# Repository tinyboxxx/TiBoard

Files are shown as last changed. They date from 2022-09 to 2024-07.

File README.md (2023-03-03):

# TiBoard
>  TiBoard的硬件部分及说明文件

- merged SofleKeyboard and nrfBoard
- reserved place for trackpoint
- position of keys moved to my hand measurements
- carbon fiber top plate
- Voronoi style 3D print keycap

打包的KiCAD如果有什么问题麻烦发issue。

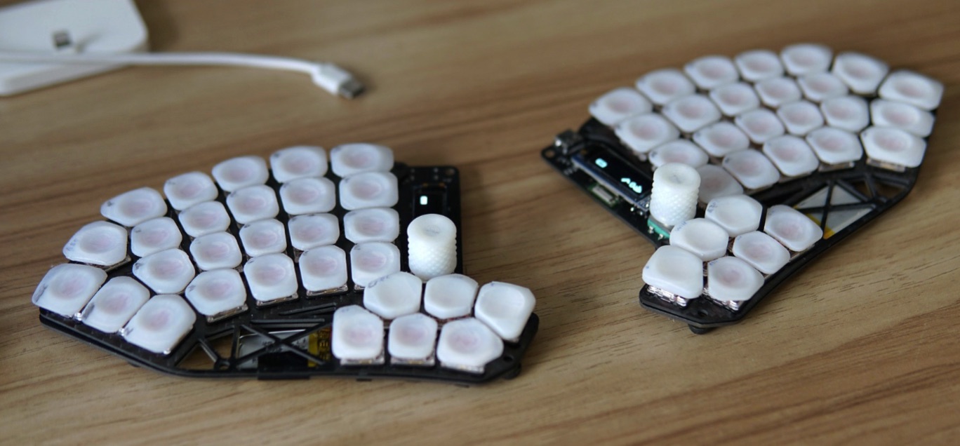
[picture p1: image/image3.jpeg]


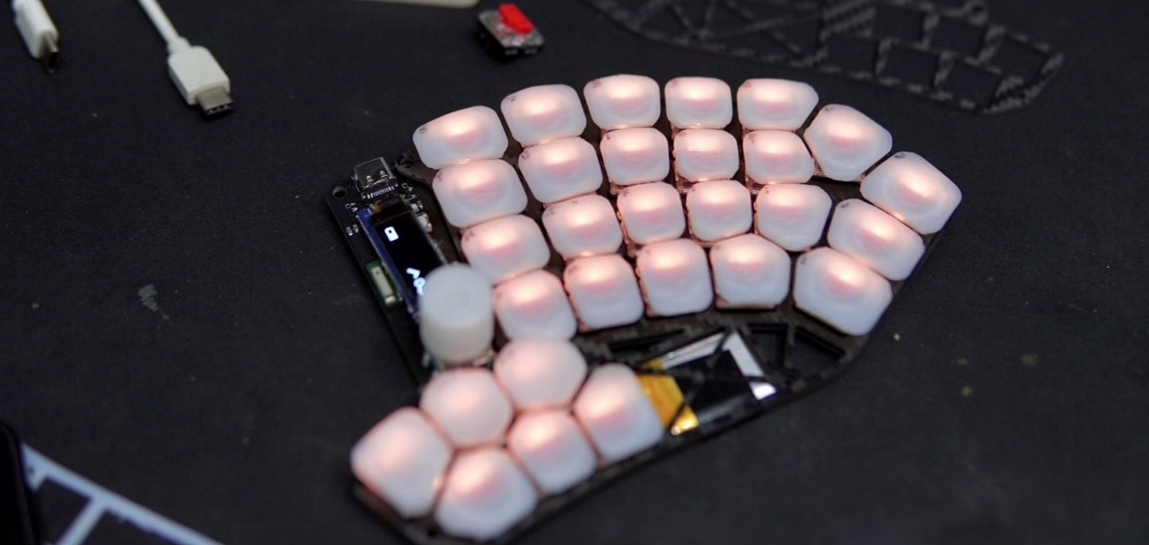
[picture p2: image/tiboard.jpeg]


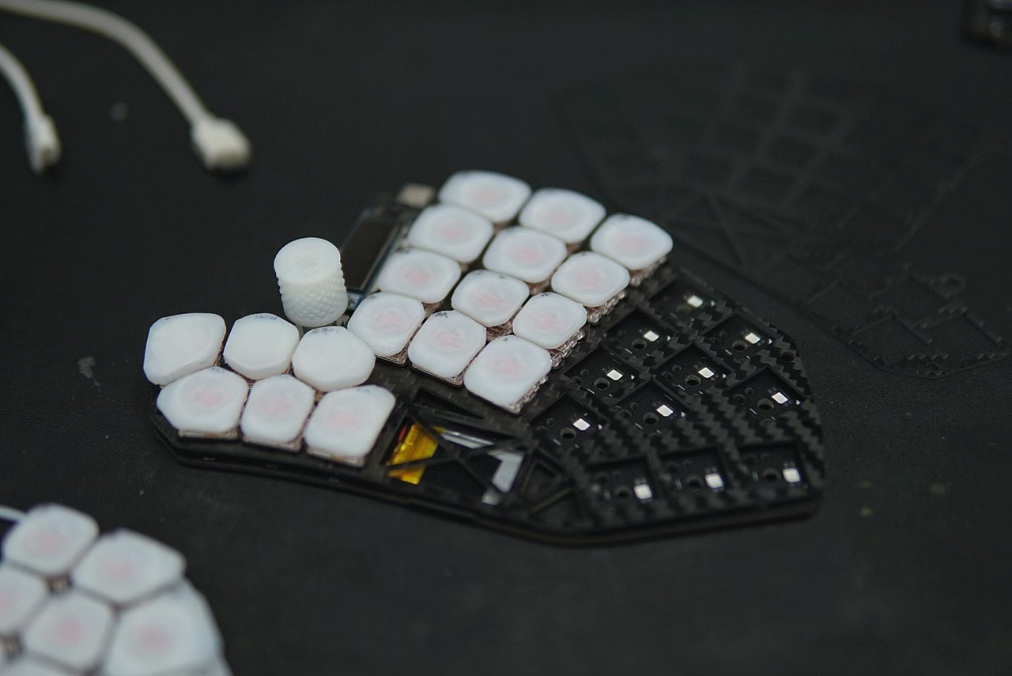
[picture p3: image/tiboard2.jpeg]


## 许可

可以自己随便做着玩。

空板交易无所谓，不要闲鱼卖套件，不要卖成品。

转载和修改版请带上我的名字。

## 需要注意购买的零件

**注意：为单套，左右手两只的数量需要x2 ！**

| 项目 | 备注 | 数量（单个板） | 链接 |
| --- | --- | --- | --- |
| E73蓝牙模块（PCB内） | E73-2G4M08S1C | 1 | https://m.tb.cn/h.UL6DjRC  亿佰特nRF52840/52833芯片无线蓝牙MESH模块BLE4.2/5.0陶瓷天线 |
| 锂电池 | 402030（长30宽20厚4）不一定非要这家店，同尺寸带保护板即可。  | 1 | https://m.tb.cn/h.Upcs7Os  伯朗 导航行车记录仪锂电池大容量通用3.7v聚合物 |
| 轴体 | 必须凯华1350型号，颜色任选 | 30 | https://m.tb.cn/h.UK0Awu7  凯华Kailh 1350巧克力机械键盘轴体  |
| 轴体热插拔底座 | 必须凯华1350型号 | 30 | https://item.taobao.com/item.htm?id=667154671807 |
| 定位板 | 厚度1.2mm，dxf文件见附件，参考价格碳纤维RMB68两片。也可以使用玻纤等其他不导电材料。 | 1 | https://item.taobao.com/item.htm?id=40340403528 |

## 状态及已知问题

BOM里充电电流设定用的R9 现在用的是2.2K，二极管是1N4148WS。

有其他疑问也请发issue。

已知问题：

- 目前使用的电池功耗大约1至2天，建议随时充电。
- 键位比较少 符号和其他按键不大方便。
- reset按钮位置比较难按。
- USB Type-C接口没有做沉板，左手的接口比较靠近桌子。
- 电池接插件比较大，目前直接焊线。
- I2C的两个电阻实测可以不焊接。
- 烧录E73模块真的很麻烦，需要先刷ST-LINK的固件 或者用STM32
- 指点杆的安装比较麻烦，而且可能影响厚度，兼容性还未测试。

## 链接

固件 https://github.com/tinyboxxx/zmk-config

固件下载 https://github.com/tinyboxxx/zmk-config/actions

键位编辑器 [ZMK Keymap Editor (nickcoutsos.github.io)](https://nickcoutsos.github.io/keymap-editor/)

视频 https://www.bilibili.com/video/BV1qe4y1t7zE/

烧录bootloader https://github.com/joric/nrfmicro/wiki/Bootloader#nrf52840

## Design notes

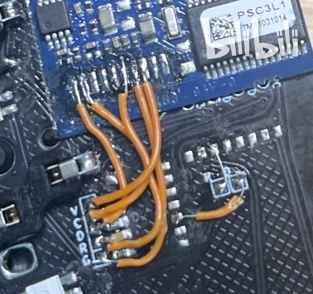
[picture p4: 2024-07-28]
Tiboard/Snipaste_2024-07-28_22-50-21.png

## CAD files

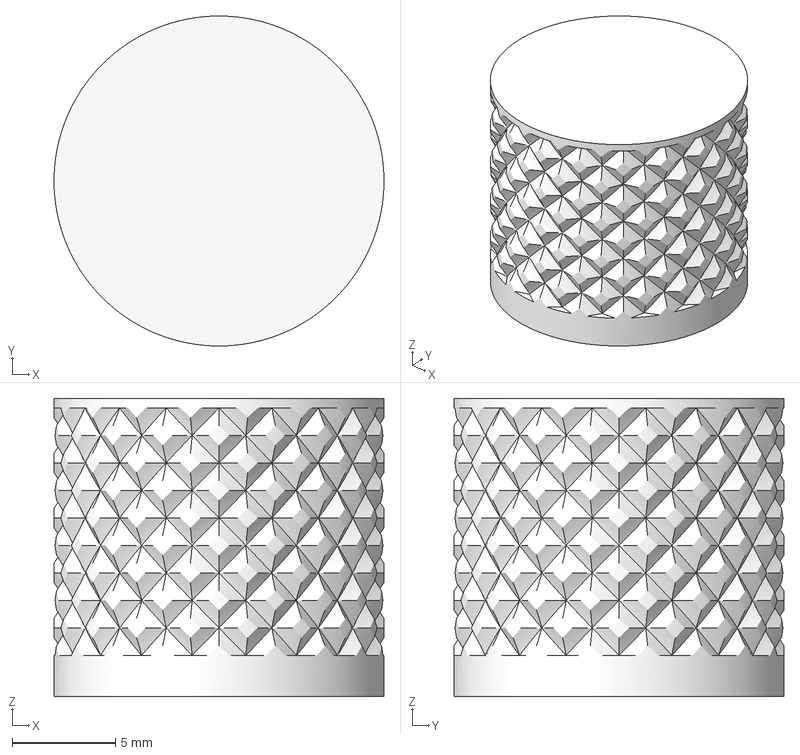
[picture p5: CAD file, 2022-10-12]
2. 3D - Fusion360/编码器帽.3mf
16.0 x 16.0 x 14.5 mm

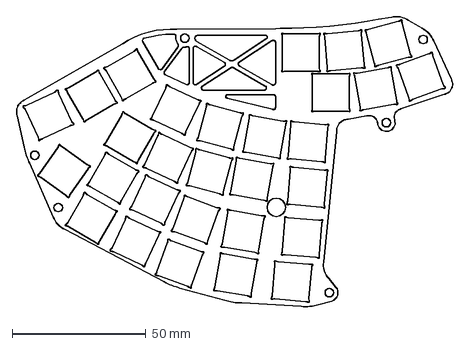
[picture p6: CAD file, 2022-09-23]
3. Top Board - DXF/1.2mm厚度 两个 正反面.dxf
162.9 x 108.4 mm

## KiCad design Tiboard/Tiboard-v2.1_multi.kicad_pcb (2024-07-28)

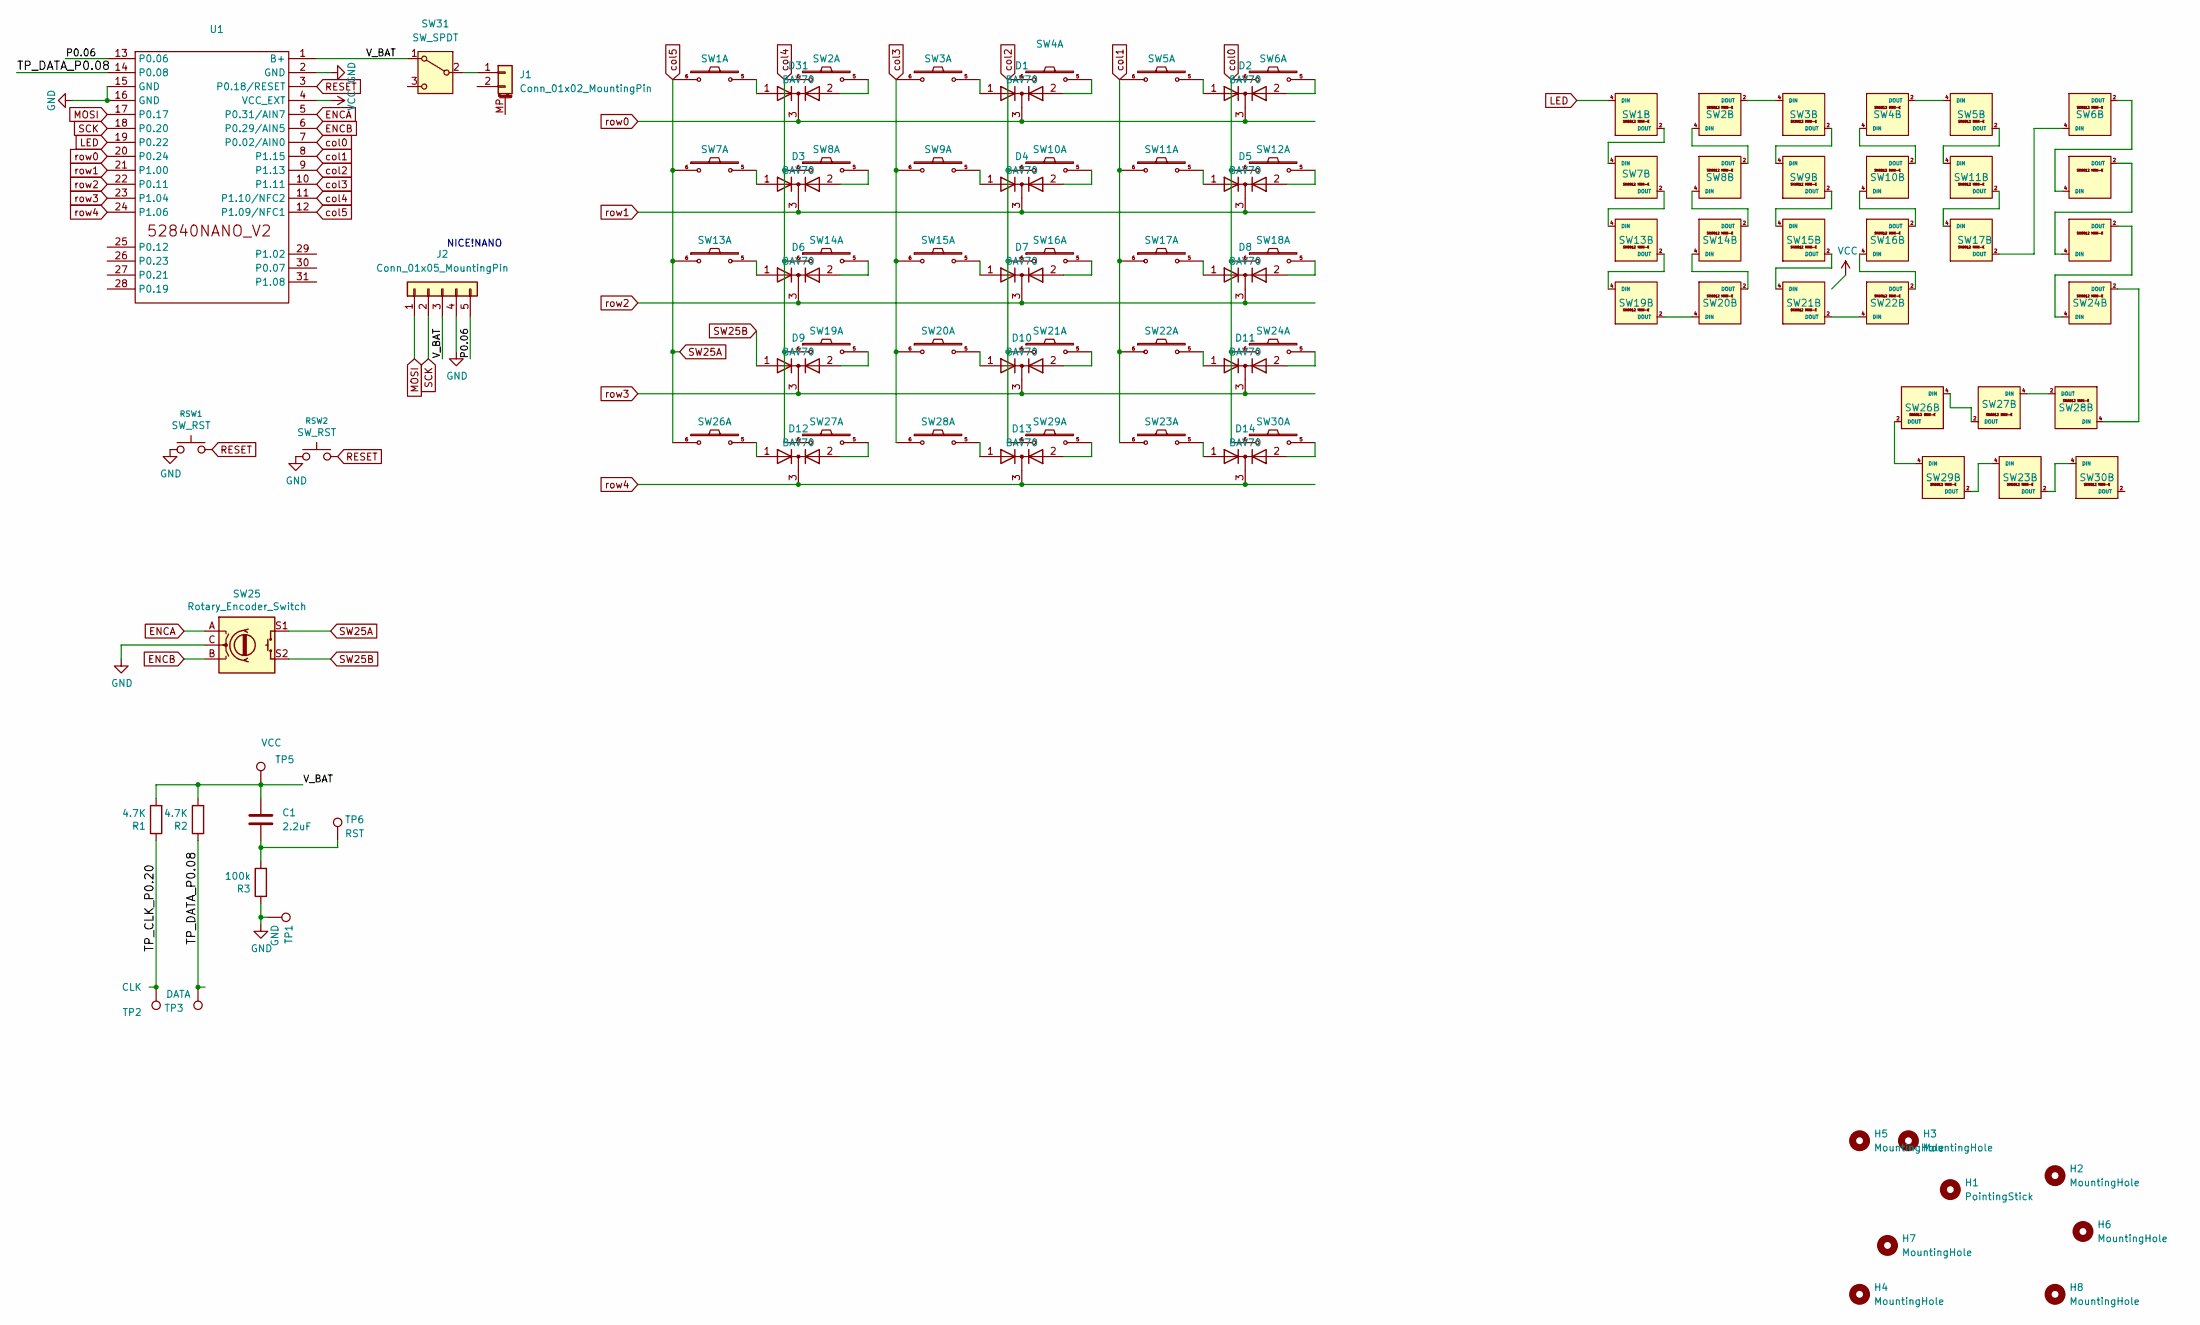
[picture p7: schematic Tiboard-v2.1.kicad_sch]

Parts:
C1: 2.2uF; C_0603_1608Metric
D1, D2, D3, D4, D5, D6, D7, D8, D9, D10, D11, D12, D13, D14, D31: BAV70; SOT-23
H1: PointingStick; Pointing_Stick
H2, H3, H4, H5, H6, H7, H8: MountingHole; MountingHole_3.2mm_M3_Pad_Via
J1: Conn_01x02_MountingPin; JST_SHL_SM02B-SHLS-TF_1x02-1MP_P1.00mm_Horizontal
J2: Conn_01x05_MountingPin; NICEVIEW_5Pin
R1, R2: 4.7K; R_0603_1608Metric
R3: 100k; R_0603_1608Metric
RSW1, RSW2: SW_RST; SW_SPST_CK_KXT3
SW1, SW2, SW3, SW4, SW5, SW6, SW7, SW8, SW9, SW10, SW11, SW12, SW13, SW14, SW15, SW16, SW17, SW18, SW19, SW20, SW21, SW22, SW23, SW24, SW26, SW27, SW28, SW29, SW30: SW_PUSH_LED; TTC_mini
SW25: Rotary_Encoder_Switch; RotaryEncoder_Alps_EC11E-Switch_Vertical_H20mm-keebio_modif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
SW31: SW_SPDT; SW_Slide_SPDT_Angled_CK_OS102011MA1Q
TP1: GND; TestPoint_Pad_1.0x1.0mm
TP2: CLK; TestPoint_Pad_1.0x1.0mm
TP3: DATA; TestPoint_Pad_1.0x1.0mm
TP5: VCC; TestPoint_Pad_1.0x1.0mm
TP6: RST; TestPoint_Pad_1.0x1.0mm
U1: 52840NANO_V2

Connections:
/P0.06: J2.5, U1.13 (P0.06)
ENCA: SW25.A, U1.5 (P0.31/AIN7)
ENCB: SW25.B, U1.6 (P0.29/AIN5)
LED: SW1.4 (DIN), U1.19 (P0.22)
unnamed: C1.2, R3.2, TP6.1
unnamed: D1.1 (A), SW3.5
unnamed: D1.2 (A), SW4.5
unnamed: D2.1 (A), SW5.5
unnamed: D2.2 (A), SW6.5
unnamed: D3.1 (A), SW7.5
unnamed: D3.2 (A), SW8.5
unnamed: D4.1 (A), SW9.5
unnamed: D4.2 (A), SW10.5
unnamed: D5.1 (A), SW11.5
unnamed: D5.2 (A), SW12.5
unnamed: D6.1 (A), SW13.5
unnamed: D6.2 (A), SW14.5
unnamed: D7.1 (A), SW15.5
unnamed: D7.2 (A), SW16.5
unnamed: D8.1 (A), SW17.5
unnamed: D8.2 (A), SW18.5
unnamed: D9.2 (A), SW19.5
unnamed: D10.1 (A), SW20.5
unnamed: D10.2 (A), SW21.5
unnamed: D11.1 (A), SW22.5
unnamed: D11.2 (A), SW24.5
unnamed: D12.1 (A), SW26.5
unnamed: D12.2 (A), SW27.5
unnamed: D13.1 (A), SW28.5
unnamed: D13.2 (A), SW29.5
unnamed: D14.1 (A), SW23.5
unnamed: D14.2 (A), SW30.5
unnamed: D31.1 (A), SW1.5
unnamed: D31.2 (A), SW2.5
unnamed: J1.1, SW31.2 (B)
unnamed: SW1.2 (DOUT), SW7.4 (DIN)
unnamed: SW2.4 (DIN), SW8.2 (DOUT)
unnamed: SW2.2 (DOUT), SW3.4 (DIN)
unnamed: SW3.2 (DOUT), SW9.4 (DIN)
unnamed: SW4.2 (DOUT), SW5.4 (DIN)
unnamed: SW10.4 (DIN), SW16.2 (DOUT)
unnamed: SW4.4 (DIN), SW10.2 (DOUT)
unnamed: SW5.2 (DOUT), SW11.4 (DIN)
unnamed: SW11.2 (DOUT), SW17.4 (DIN)
unnamed: SW6.2 (DOUT), SW12.4 (DIN)
unnamed: SW12.2 (DOUT), SW18.4 (DIN)
unnamed: SW7.2 (DOUT), SW13.4 (DIN)
unnamed: SW13.2 (DOUT), SW19.4 (DIN)
unnamed: SW14.4 (DIN), SW20.2 (DOUT)
unnamed: SW8.4 (DIN), SW14.2 (DOUT)
unnamed: SW9.2 (DOUT), SW15.4 (DIN)
unnamed: SW15.2 (DOUT), SW21.4 (DIN)
unnamed: SW16.4 (DIN), SW22.2 (DOUT)
unnamed: SW6.4 (DIN), SW17.2 (DOUT)
unnamed: SW18.2 (DOUT), SW24.4 (DIN)
unnamed: SW19.2 (DOUT), SW20.4 (DIN)
unnamed: SW21.2 (DOUT), SW22.4 (DIN)
unnamed: SW23.4 (DIN), SW29.2 (DOUT)
unnamed: SW23.2 (DOUT), SW30.4 (DIN)
unnamed: SW24.2 (DOUT), SW28.4 (DIN)
unnamed: SW26.4 (DIN), SW27.2 (DOUT)
unnamed: SW26.2 (DOUT), SW29.4 (DIN)
unnamed: SW27.4 (DIN), SW28.2 (DOUT)
RESET: RSW1.2, RSW2.2, U1.3 (P0.18/RESET)
SCL: J2.2, U1.18 (P0.20)
SDA: J2.1, U1.17 (P0.17)
SW25A: SW1.6, SW7.6, SW13.6, SW25.S1, SW26.6, U1.12 (P1.09/NFC1)
SW25B: D9.1 (A), SW25.S2
VCC: SW1.1 (VDD), SW2.1 (VDD), SW3.1 (VDD), SW4.1 (VDD), SW5.1 (VDD), SW6.1 (VDD), SW7.1 (VDD), SW8.1 (VDD), SW9.1 (VDD), SW10.1 (VDD), SW11.1 (VDD), SW12.1 (VDD), SW13.1 (VDD), SW14.1 (VDD), SW15.1 (VDD), SW16.1 (VDD), SW17.1 (VDD), SW18.1 (VDD), SW19.1 (VDD), SW20.1 (VDD), SW21.1 (VDD), SW22.1 (VDD), SW23.1 (VDD), SW24.1 (VDD), SW26.1 (VDD), SW27.1 (VDD), SW28.1 (VDD), SW29.1 (VDD), SW30.1 (VDD), U1.4 (VCC_EXT)
col0: SW6.6, SW12.6, SW18.6, SW24.6, SW30.6, U1.7 (P0.02/AIN0)
col1: SW5.6, SW11.6, SW17.6, SW22.6, SW23.6, U1.8 (P1.15)
col2: SW4.6, SW10.6, SW16.6, SW21.6, SW29.6, U1.9 (P1.13)
col3: SW3.6, SW9.6, SW15.6, SW20.6, SW28.6, U1.10 (P1.11)
col4: SW2.6, SW8.6, SW14.6, SW19.6, SW27.6, U1.11 (P1.10/NFC2)
row0: D1.3 (K), D2.3 (K), D31.3 (K), U1.20 (P0.24)
row1: D3.3 (K), D4.3 (K), D5.3 (K), U1.21 (P1.00)
row2: D6.3 (K), D7.3 (K), D8.3 (K), U1.22 (P0.11)
row3: D9.3 (K), D10.3 (K), D11.3 (K), U1.23 (P1.04)
row4: D12.3 (K), D13.3 (K), D14.3 (K), U1.24 (P1.06)

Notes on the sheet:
NICE!NANO

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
Board: 2 copper layers, 71 parts (9 on the bottom side), 83 nets, no tracks yet.

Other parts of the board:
TP4: DATA; TestPoint_Pad_1.0x1.0mm
TP7: GND; TestPoint_Pad_1.0x1.0mm
kibuzzard-62E281FD: G***; kibuzzard-62E281FD

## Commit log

2022-09-23 gerber added
    从华秋下载下来的gerber
2022-09-23 file update
    顶板目前有点紧 安装比较麻烦
    [1.2mm厚度 两个 正反面.dxf]
2022-10-12 开源上传
    [Tiboard.kicad_sch, 编码器帽.3mf]
2023-03-01 BOM added
2024-07-28 Tiboard V2 developing
    [Tiboard-v2.1.kicad_sch]
2024-07-28 day1 for Tiboard V2
    [Tiboard-v2.1.kicad_sch, Tiboard-v2.1_multi.kicad_pcb, Tiboard.dsn]
